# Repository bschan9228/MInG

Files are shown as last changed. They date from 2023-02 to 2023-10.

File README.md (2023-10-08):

# MInG
MInG is a hardware password manager. More information can be found below: 

https://bschan9228.github.io/MInG/

https://docs.google.com/document/d/1XQeUcRW4mPYvgZ0W_UPjm9wVBVjZgWeWX6C9jlaiZSg/edit



## Folder Structure
    .
    ├── Hardware                # Project hardware and PCB
    │   ├── Final               # Final PCB 
    │   └── Prototype           # Prototype PCB's
    └── Software
            ├── Experimental    # Experimental firmware for the device
            └── Final           # Final firmware for the device

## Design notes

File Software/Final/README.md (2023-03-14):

# Final Software
Finalized software for MInG. Built with ESP-IDF.

Default access point username: MInG 

Default access point password: mypassword 



## Features

### Password Management System
- Stores all credentials in flash memory
- Search bar to look up credentials
- Add new credentials through form
- Delete button to remove credentials
- 192.168.4.1/pm

<kbd></kbd>

### Config
- Change SSID's name and password
  - Stored in NVS
  - Please use reasonable SSID name/password, otherwise device may not work
- Send any HID text wirelessly
- 192.168.4.1

<kbd></kbd>

### Keyboard
- Type any character into target device. Worked on all tested USB-A and USB-C devices that supports keyboards
- Only characters and special characters have been implemented (no delete, tab, F-keys, etc.)
- Only typing on a physical keyboard has been implemented. Tapping on the virtual keyboard will not work. 
- 192.168.4.1/keyboard

<kbd></kbd>

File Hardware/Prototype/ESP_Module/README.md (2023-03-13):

# Module
Working ESP32-S3 Module USB-A device.



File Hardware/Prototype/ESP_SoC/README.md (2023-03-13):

# SoC
A working ESP32-S3 PCB with featuring USB-A and USB-C connectors.



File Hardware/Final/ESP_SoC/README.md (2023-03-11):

# Final PCB
Final PCB design for the ESP32 PCB. Currently Have not been produced. Includes reverse polarity protection.

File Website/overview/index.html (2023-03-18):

Home (https://bschan9228.github.io/MInG/index.html)

Projects ⟱

Projects overview (https://bschan9228.github.io/MInG/Website/overview/index.html) Projects Video (https://bschan9228.github.io/MInG/Website/Video/index.html) References (https://bschan9228.github.io/MInG/Website/References/index.html)

Technical Workshop ⟱

Embedding the Embedded (https://bschan9228.github.io/MInG/Website/workshop/index.html)

About us (https://bschan9228.github.io/MInG/Website/us/index.html)

## Presentation Slides

## Project Poster

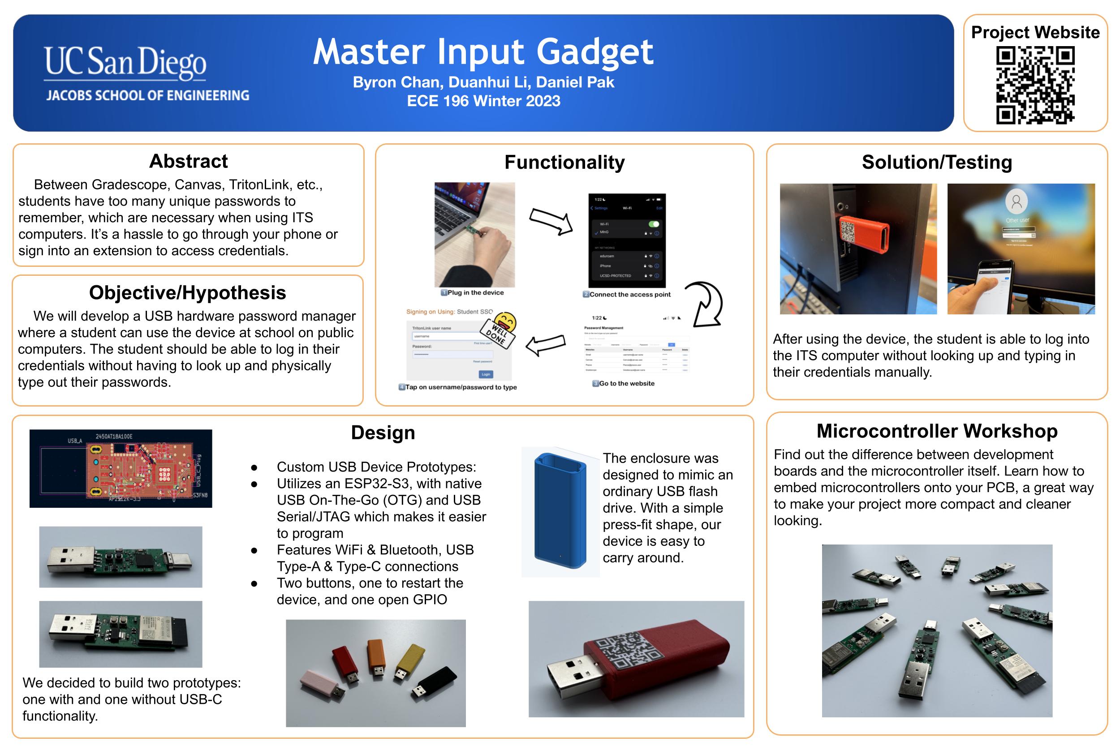
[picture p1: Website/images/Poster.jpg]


## Work flow

This is how our device works



## ESP32-S3 SoC PCB

For our project, we used the ESP32-S3 MCU, which supports USB OTG and is capable of 2.4 GHz Wi-Fi and Bluetooth Low Energy 5.0





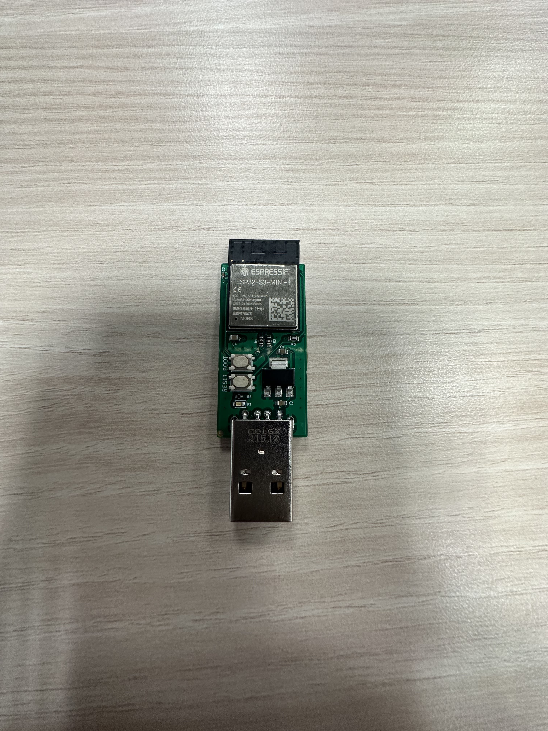
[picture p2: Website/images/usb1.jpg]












© UC San Diego: Jacobs School of Enginnering

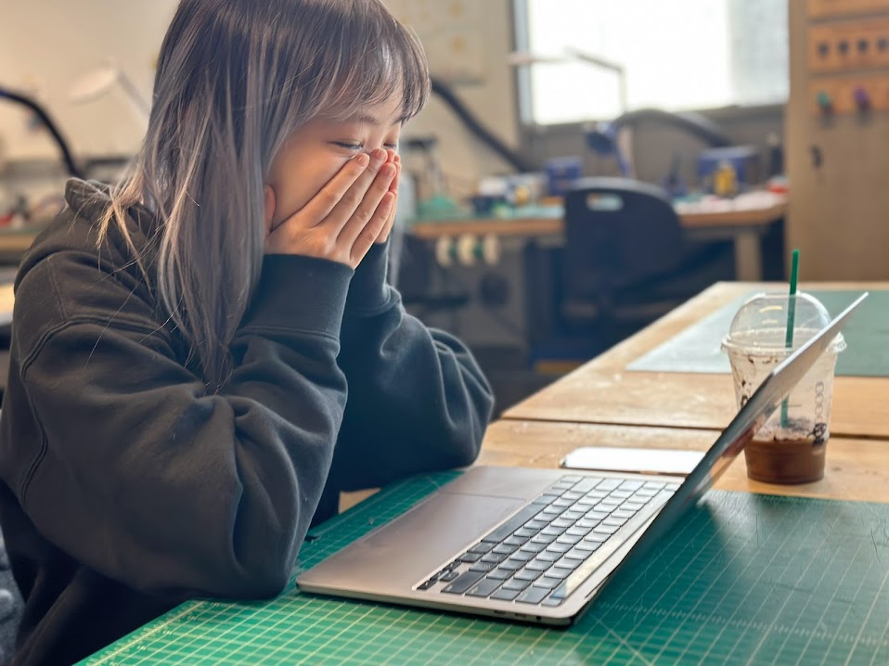
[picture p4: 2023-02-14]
Website/images/lori.png

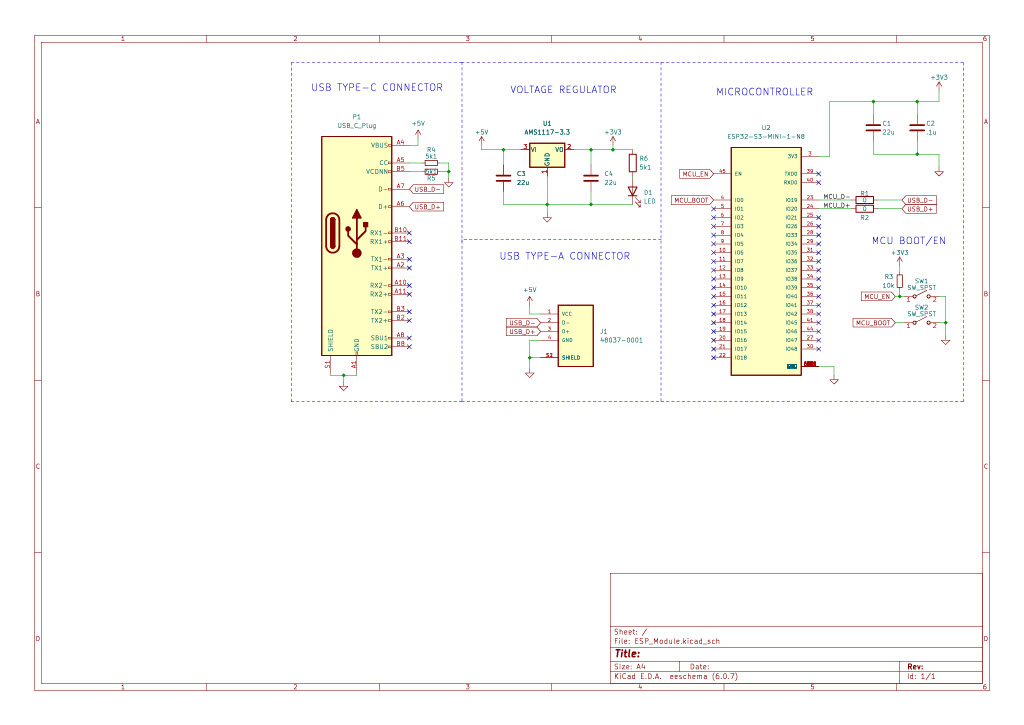
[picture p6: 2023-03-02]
Website/images/pcb1.jpg

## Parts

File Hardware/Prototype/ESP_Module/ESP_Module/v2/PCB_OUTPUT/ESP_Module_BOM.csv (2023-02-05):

Comment | Designator | Footprint | LCSC Part #
22u Unpolarized capacitor | C1,C3,C4 | C_0603_1608Metric | C59461
.1u Unpolarized capacitor | C2 | C_0402_1005Metric | C1525
LED Light emitting diode | D1 | LED_0603_1608Metric | C72043
48037-0001 | J1 | MOLEX_48037-0001 | C136455
USB_C_Plug USB Type-C Plug connector | P1 | USB_C_Plug_Molex_105444 | C319150
0 Resistor | R1,R2 | R_0603_1608Metric | C17168
10k Resistor, small symbol | R3 | R_0603_1608Metric | C25744
5k1 Resistor | R4,R5,R6 | R_0402_1005Metric | C25905
SW_SPST Single Pole Single Throw (SPST) switch | SW1,SW2 | SW_SPST_PTS810 | C92589
AMS1117-3.3 1A Low Dropout regulator, positive, 3.3V fixed output, SOT-223 | U1 | SOT-223-3_TabPin2 | C6186
ESP32-S3-MINI-1-N8 | U2 | XCVR_ESP32-S3-MINI-1-N8 | C2913206

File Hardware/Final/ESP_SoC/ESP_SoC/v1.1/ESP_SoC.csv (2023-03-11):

Comment | Designator | Footprint | LCSC Part # | Quantity
2450AT18A100E | AE1 | ANTC3216X140N | C89334 | 1 | =E2*F1
1u Unpolarized capacitor, small symbol | C1,C7,C11,C12,C13,C16 | C_0402_1005Metric | C52923 | 6 | =E3*F1
0.1u Unpolarized capacitor, small symbol | C2,C5,C6,C9,C10 | C_0402_1005Metric | C307331 | 5 | =E4*F1
3.3p Unpolarized capacitor, small symbol | C3,C4 | C_0402_1005Metric | C1565 | 2 | =E5*F1
10u Unpolarized capacitor, small symbol | C8 | C_0603_1608Metric | C19702 | 1 | =E6*F1
12p Unpolarized capacitor, small symbol | C14,C15 | C_0402_1005Metric | C1547 | 2 | =E7*F1
NSR0320 Schottky diode | D1,D2,D3 | D_SOD-323F | C48192 | 3 | =E8*F1
USB_A USB Type A connector | J1 | USB_A_CNCTech_1001-011-01101_Horizontal | C283548 | 1 | =E9*F1
Conn_01x01 Generic connector, single row, 01x01, script generated (kicad-library-utils/schlib/autogen/connector/) | J2,J3 | SolderWirePad_1x01_SMD_1x2mm |  | 2 | =E10*F1
2.2nH Inductor, small symbol | L1,L2 | L_0402_1005Metric | C91240 | 2 | =E11*F1
USB_C_Plug USB Type-C Plug connector | P1 | USB_C_Plug_Molex_105444 | C134082 | 1 | =E12*F1
0 Resistor, small symbol | R1,R3,R4 | R_0402_1005Metric | C17168 | 3 | =E13*F1
10k Resistor | R2 | R_0402_1005Metric | C25744 | 1 | =E14*F1
5k1 Resistor, small symbol | R5 | R_0402_1005Metric | C25905 | 1 | =E15*F1
DNP Resistor, small symbol | R6,R7 | R_0402_1005Metric |  | 2 | =E16*F1
RESET Single Pole Single Throw (SPST) switch | SW1 | SW_SPST_PTS810 | C221897 | 1 | =E17*F1
BOOT Single Pole Single Throw (SPST) switch | SW2 | SW_SPST_PTS810 | C221897 | 1 | =E18*F1
AP2112K-3.3 600mA low dropout linear regulator, with enable pin, 3.8V-6V input voltage range, 3.3V fixed positive output, SOT-23-5 | U1 | SOT-23-5 | C51118 | 1 | =E19*F1
ESP32-S3FN8 | U2 | QFN40P700X700X90-57N |  | 1 | =E20*F1
WS2812-2020 | U3 | LED_WS2812-2020 | C2976072 | 1 | =E21*F1
40MHz Four pin crystal, GND on pins 2 and 4 | Y1 | Crystal_SMD_2016-4Pin_2.0x1.6mm | C255898 | 1 | =E22*F1

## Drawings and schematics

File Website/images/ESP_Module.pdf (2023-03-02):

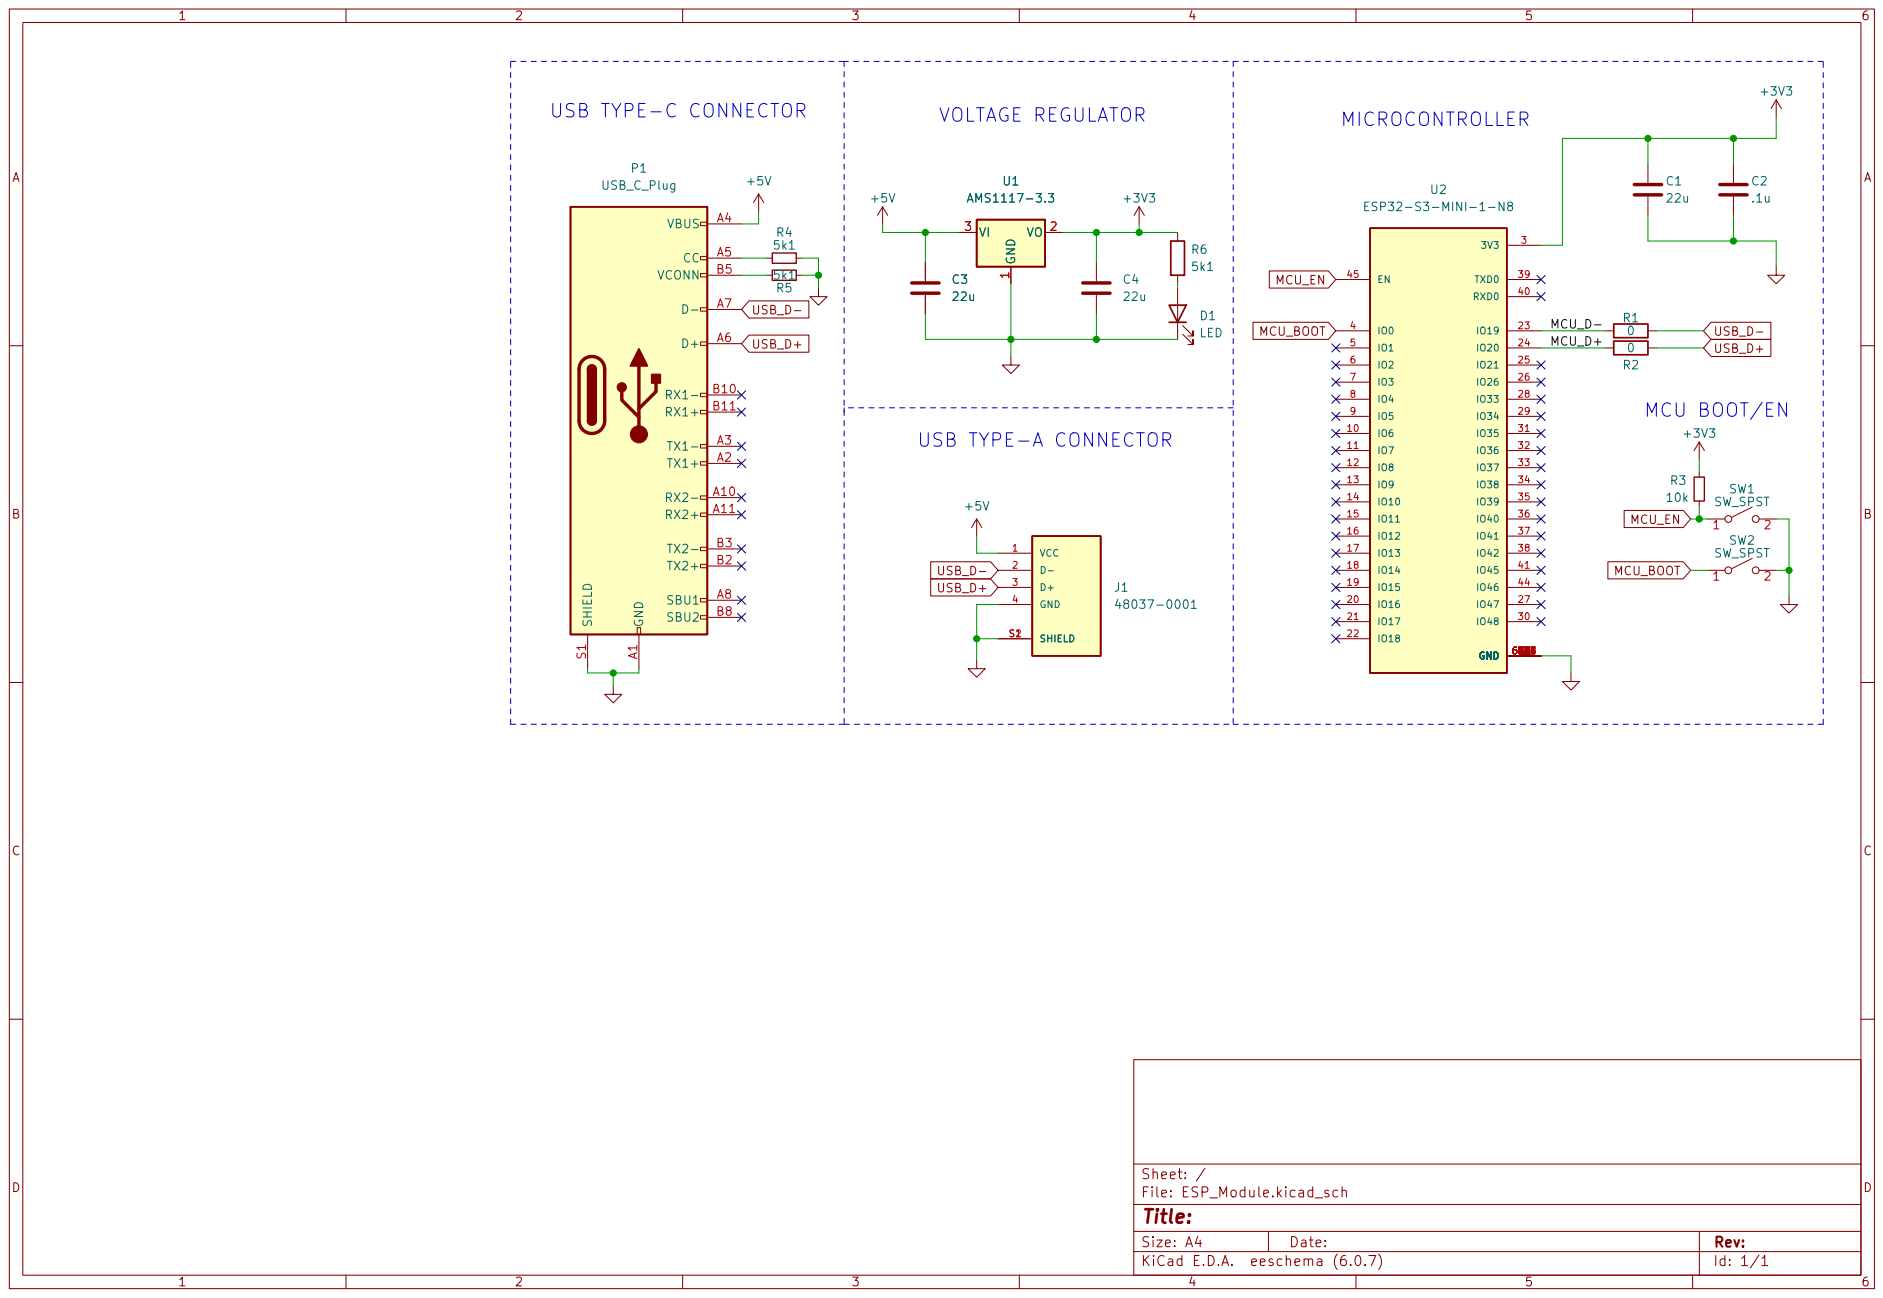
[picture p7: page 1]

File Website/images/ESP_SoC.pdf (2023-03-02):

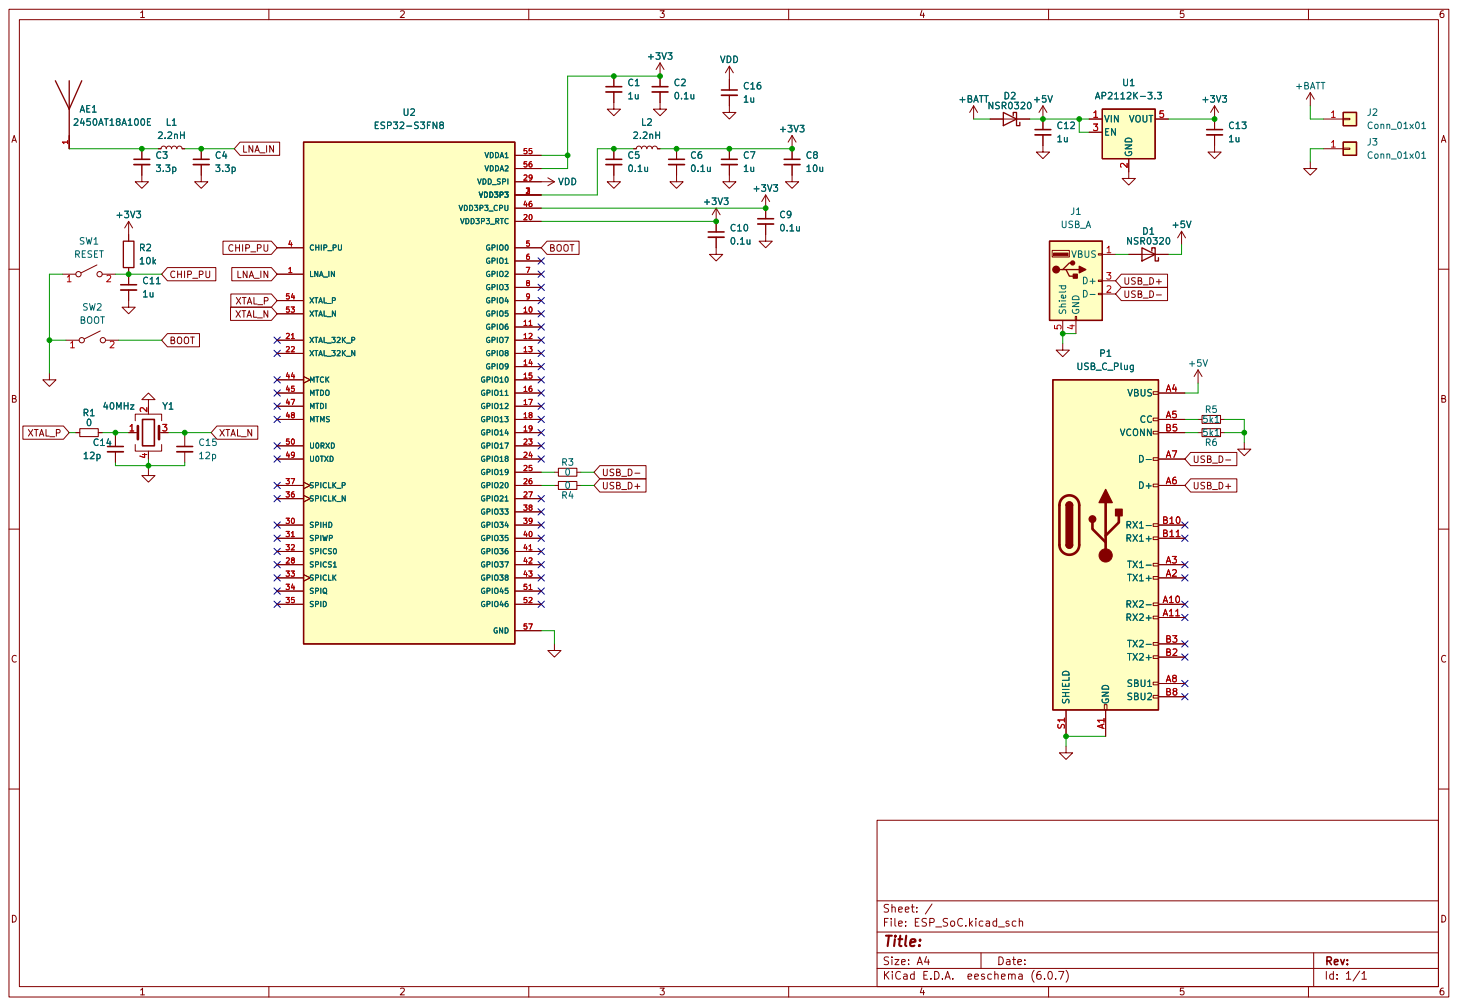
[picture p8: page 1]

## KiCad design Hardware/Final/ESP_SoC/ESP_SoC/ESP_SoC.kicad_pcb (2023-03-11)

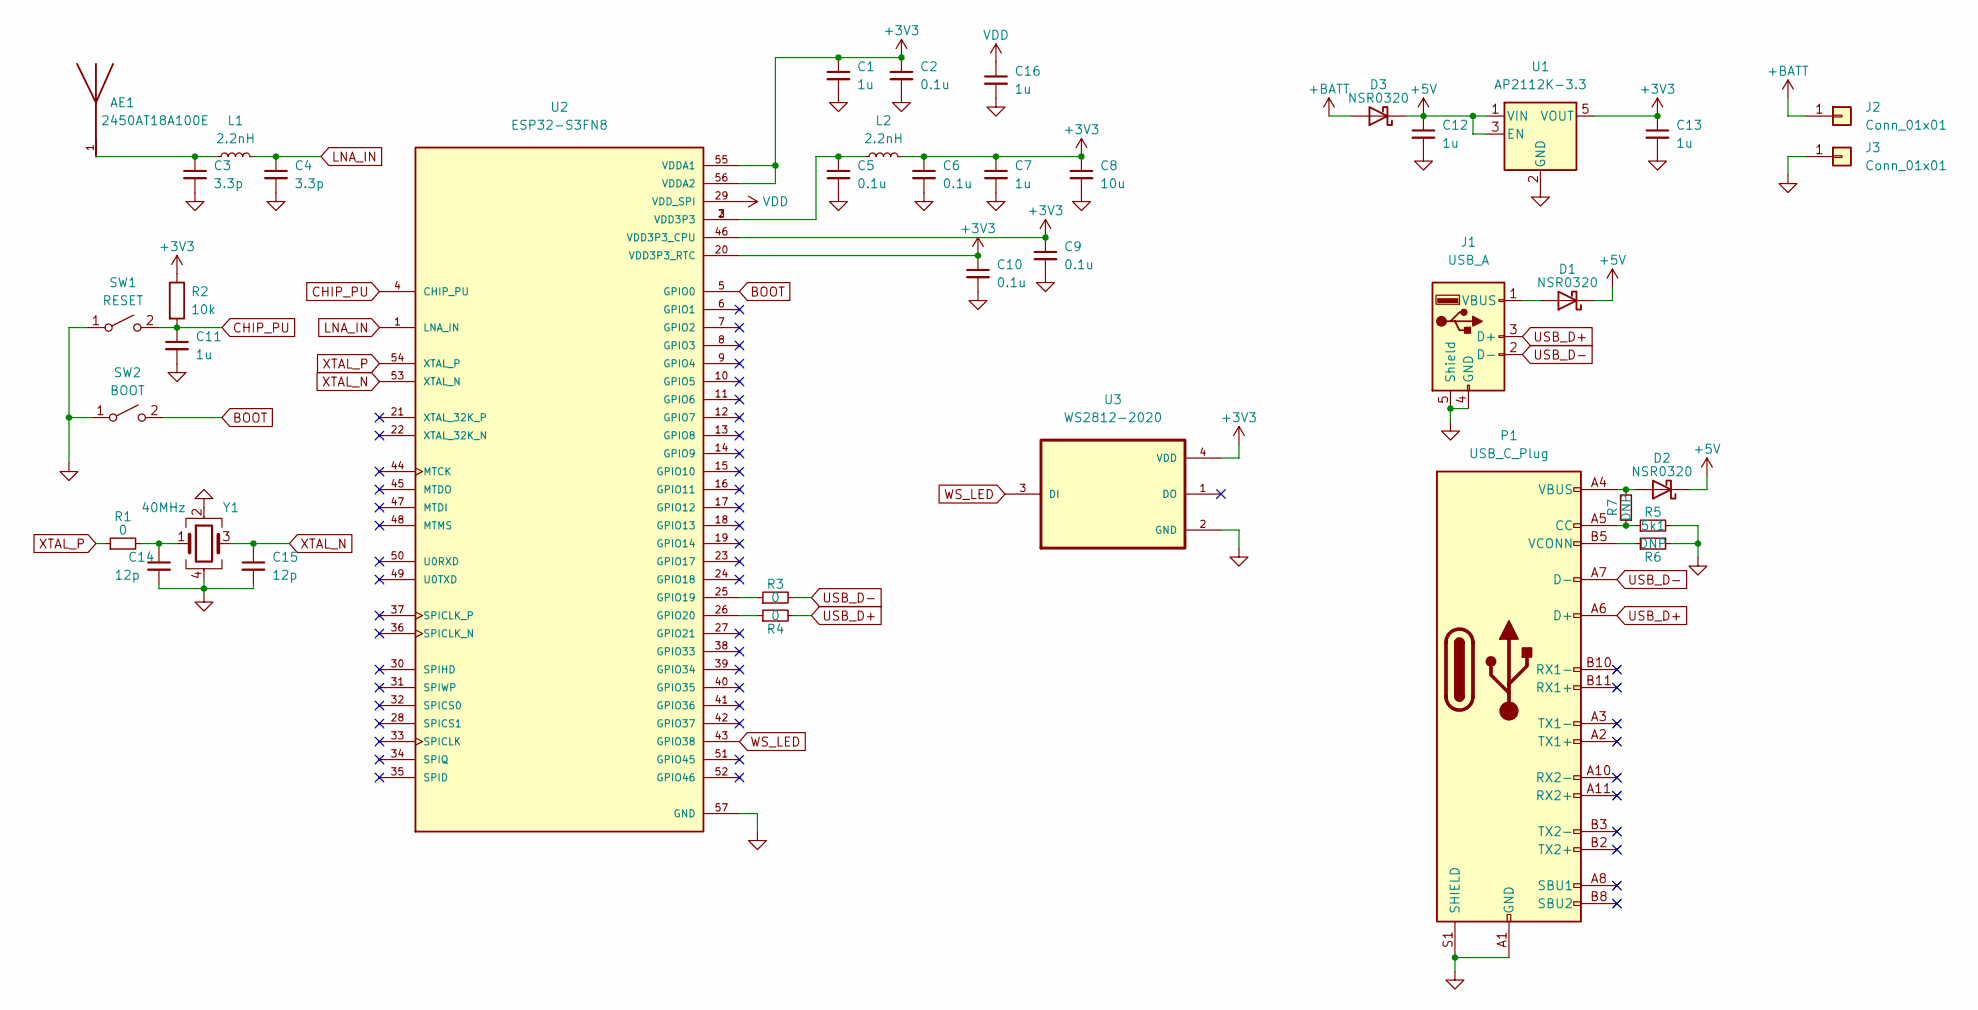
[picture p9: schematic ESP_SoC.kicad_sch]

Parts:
AE1: 2450AT18A100E; ANTC3216X140N; PARTREV 1.3; LCSC Part # C89334
C1, C7, C11, C12, C13, C16: 1u; C_0402_1005Metric; LCSC Part # C52923
C2, C5, C6, C9, C10: 0.1u; C_0402_1005Metric; LCSC Part # C307331
C3, C4: 3.3p; C_0402_1005Metric; LCSC Part # C1565
C8: 10u; C_0603_1608Metric; LCSC Part # C19702
C14, C15: 12p; C_0402_1005Metric; LCSC Part # C1547
D1, D2, D3: NSR0320; D_SOD-323F; LCSC Part # C48192
J1: USB_A; USB_A_CNCTech_1001-011-01101_Horizontal; LCSC Part # C283548
J2, J3: Conn_01x01; SolderWirePad_1x01_SMD_1x2mm
L1, L2: 2.2nH; L_0402_1005Metric; LCSC Part # C91240
P1: USB_C_Plug; USB_C_Plug_Molex_105444; LCSC Part # C134082
R1, R3, R4: 0; R_0402_1005Metric; LCSC Part # C17168
R2: 10k; R_0402_1005Metric; LCSC Part # C25744
R5: 5k1; R_0402_1005Metric; LCSC Part # C25905
R6, R7: DNP; R_0402_1005Metric
SW1: RESET; SW_SPST_PTS810; LCSC Part # C221897
SW2: BOOT; SW_SPST_PTS810; LCSC Part # C221897
U1: AP2112K-3.3; SOT-23-5; LCSC Part # C51118
U2: ESP32-S3FN8; QFN40P700X700X90-57N
U3: WS2812-2020; LED_WS2812-2020; PARTREV V1.3; LCSC Part # C2976072
Y1: 40MHz; Crystal_SMD_2016-4Pin_2.0x1.6mm; LCSC Part # C255898

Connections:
+3V3: C1.1, C2.1, C6.1, C7.1, C8.1, C9.1, C10.1, C13.1, L2.2, R2.1, U1.5 (VOUT), U2.20 (VDD3P3_RTC), U2.46 (VDD3P3_CPU), U2.55 (VDDA1), U2.56 (VDDA2), U3.4 (VDD)
+5V: C12.1, D1.1 (K), D2.1 (K), D3.1 (K), U1.1 (VIN), U1.3 (EN)
+BATT: D3.2 (A), J2.1
BOOT: SW2.2 (B), U2.5 (GPIO0)
CHIP_PU: C11.1, R2.2, SW1.2 (B), U2.4 (CHIP_PU)
GND: C1.2, C2.2, C3.2, C4.2, C5.2, C6.2, C7.2, C8.2, C9.2, C10.2, C11.2, C12.2, C13.2, C14.2, C15.2, C16.2, J1.4 (GND), J1.5 (Shield), J3.1, P1.A1 (GND), P1.A12 (GND), P1.B1 (GND), P1.B12 (GND), P1.S1 (SHIELD), R5.2, R6.2, SW1.1 (A), SW2.1 (A), U1.2 (GND), U2.57 (GND), U3.2 (GND), Y1.2, Y1.4
LNA_IN: C4.1, L1.2, U2.1 (LNA_IN)
unnamed: AE1.1, C3.1, L1.1
unnamed: C5.1, L2.1, U2.2 (VDD3P3), U2.3 (VDD3P3)
unnamed: C14.1, R1.2, Y1.1
unnamed: D1.2 (A), J1.1 (VBUS)
unnamed: D2.2 (A), P1.A4 (VBUS), P1.A9 (VBUS), P1.B4 (VBUS), P1.B9 (VBUS), R7.2
unnamed: P1.A5 (CC), R5.1, R7.1
unnamed: P1.B5 (VCONN), R6.1
unnamed: R3.1, U2.25 (GPIO19)
unnamed: R4.1, U2.26 (GPIO20)
USB_D+: J1.3 (D+), P1.A6 (D+), R4.2
USB_D-: J1.2 (D-), P1.A7 (D-), R3.2
VDD: C16.1, U2.29 (VDD_SPI)
WS_LED: U2.43 (GPIO38), U3.3 (DI)
XTAL_N: C15.1, U2.53 (XTAL_N), Y1.3
XTAL_P: R1.1, U2.54 (XTAL_P)

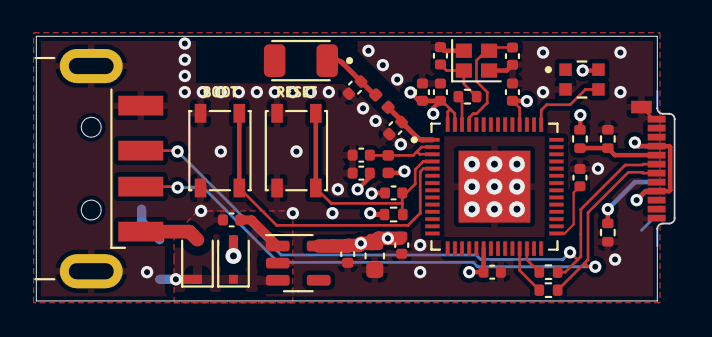
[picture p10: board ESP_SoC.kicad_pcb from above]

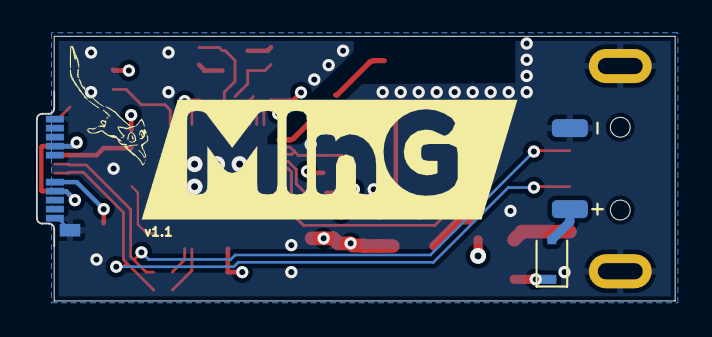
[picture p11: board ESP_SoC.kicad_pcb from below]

Board: 4 copper layers, 35.5 x 14.7 mm, 40 parts (4 on the bottom side), 22 nets.

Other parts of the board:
kibuzzard-64092D35: G***; kibuzzard-64092D35

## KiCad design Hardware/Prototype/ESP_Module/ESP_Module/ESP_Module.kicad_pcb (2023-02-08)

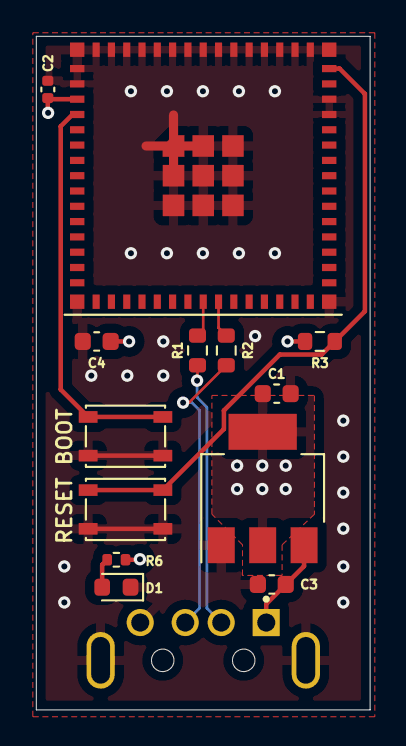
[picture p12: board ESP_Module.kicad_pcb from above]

Board: 4 copper layers, 18.5 x 37.4 mm, 14 parts (0 on the bottom side), 10 nets.

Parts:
C1, C3, C4: 22u; C_0603_1608Metric
C2: .1u; C_0402_1005Metric
D1: LED; LED_0603_1608Metric
J1: 48037-0001; MOLEX_48037-0001
R1, R2: 0; R_0603_1608Metric
R3: 10k; R_0603_1608Metric
R6: 5k1; R_0402_1005Metric
SW1, SW2: SW_SPST; SW_SPST_PTS810
U1: AMS1117-3.3; SOT-223-3_TabPin2
U2: ESP32-S3-MINI-1-N8; XCVR_ESP32-S3-MINI-1-N8

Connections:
+3V3: C1.1, C2.1, C4.1, R3.1, R6.1, U1.2 (VO), U2.3 (3V3)
+5V: C3.1, J1.1 (VCC), U1.3 (VI)
/MCU_D+: R2.1, U2.24 (IO20)
/MCU_D-: R1.1, U2.23 (IO19)
GND: C1.2, C2.2, C3.2, C4.2, D1.1 (K), J1.4 (GND), J1.S1 (SHIELD), J1.S2 (SHIELD), SW1.2 (B), SW2.2 (B), U1.1 (GND), U2.1 (GND), U2.2 (GND), U2.42 (GND), U2.43 (GND), U2.46 (GND), U2.47 (GND), U2.48 (GND), U2.49 (GND), U2.50 (GND), U2.51 (GND), U2.52 (GND), U2.53 (GND), U2.54 (GND), U2.55 (GND), U2.56 (GND), U2.57 (GND), U2.58 (GND), U2.59 (GND), U2.60 (GND), U2.61 (GND), U2.61_1 (GND), U2.61_2 (GND), U2.61_3 (GND), U2.61_4 (GND), U2.61_5 (GND), U2.61_6 (GND), U2.61_7 (GND), U2.61_8 (GND), U2.62 (GND), U2.63 (GND), U2.64 (GND), U2.65 (GND)
MCU_BOOT: SW2.1 (A), U2.4 (IO0)
MCU_EN: R3.2, SW1.1 (A), U2.45 (EN)
unnamed: D1.2 (A), R6.2
USB_D+: J1.3 (D+), R2.2
USB_D-: J1.2 (D-), R1.2

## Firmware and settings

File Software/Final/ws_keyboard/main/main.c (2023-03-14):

#include <esp_wifi.h>
#include <esp_event.h>
#include <esp_log.h>
#include <esp_system.h>
#include <nvs_flash.h>
#include <sys/param.h>
#include "esp_netif.h"
#include "esp_eth.h"

#include <esp_http_server.h>

#include <string.h>
#include "freertos/FreeRTOS.h"
#include "freertos/task.h"
#include "esp_mac.h"

#include "lwip/err.h"
#include "lwip/sys.h"

#include <stdlib.h>
#include "tinyusb.h"
#include "class/hid/hid_device.h"
#include "driver/gpio.h"

#include <cJSON.h>

#include <stdio.h>
#include "esp_vfs.h"
#include "esp_vfs_fat.h"

#include <inttypes.h>
#include "esp_system.h"
#include "nvs_flash.h"
#include "nvs.h"

extern const char root_start[] asm("_binary_root_html_start");
extern const char root_end[] asm("_binary_root_html_end");
extern const char root_js_start[] asm("_binary_root_js_start");
extern const char root_js_end[] asm("_binary_root_js_end");

extern const char keyboard_start[] asm("_binary_keyboard_html_start");
extern const char keyboard_end[] asm("_binary_keyboard_html_end");
extern const char keyboard_js_start[] asm("_binary_keyboard_js_start");
extern const char keyboard_js_end[] asm("_binary_keyboard_js_end");

extern const char pm_start[] asm("_binary_pm_html_start");
extern const char pm_end[] asm("_binary_pm_html_end");
extern const char pm_js_start[] asm("_binary_pm_js_start");
extern const char pm_js_end[] asm("_binary_pm_js_end");

#define EXAMPLE_ESP_WIFI_SSID CONFIG_ESP_WIFI_SSID
#define EXAMPLE_ESP_WIFI_PASS CONFIG_ESP_WIFI_PASSWORD
#define EXAMPLE_ESP_WIFI_CHANNEL CONFIG_ESP_WIFI_CHANNEL
#define EXAMPLE_MAX_STA_CONN CONFIG_ESP_MAX_STA_CONN

// WL + FATFS
static wl_handle_t s_wl_handle = WL_INVALID_HANDLE;
const char *base_path = "/spiflash";

static const char *TAG = "console";

//------------------------- JSON -------------------------//
char *create_user(char *application, char *username)
{
    char *string = NULL;
    cJSON *app = NULL;
    cJSON *type = NULL;
    cJSON *website = NULL;
    cJSON *data = NULL;

    cJSON *user = cJSON_CreateObject();

    app = cJSON_CreateString("pm");
    cJSON_AddItemToObject(user, "app", app);

    type = cJSON_CreateString("insertUser");
    cJSON_AddItemToObject(user, "type", type);

    website = cJSON_CreateString(application);
    cJSON_AddItemToObject(user, "website", website);

    data = cJSON_CreateString(username);
    cJSON_AddItemToObject(user, "data", data);

    string = cJSON_Print(user);

    return string;
}

//------------------------- USB HID -------------------------//

#define TUSB_DESC_TOTAL_LEN (TUD_CONFIG_DESC_LEN + CFG_TUD_HID * TUD_HID_DESC_LEN)

/**
 * @brief HID report descriptor
 *
 * In this example we implement Keyboard + Mouse HID device,
 * so we must define both report descriptors
 */
const uint8_t hid_report_descriptor[] = {
    TUD_HID_REPORT_DESC_KEYBOARD(HID_REPORT_ID(HID_ITF_PROTOCOL_KEYBOARD)),
    TUD_HID_REPORT_DESC_MOUSE(HID_REPORT_ID(HID_ITF_PROTOCOL_MOUSE))};

/**
 * @brief Configuration descriptor
 *
 * This is a simple configuration descriptor that defines 1 configuration and 1 HID interface
 */
static const uint8_t hid_configuration_descriptor[] = {
    // Configuration number, interface count, string index, total length, attribute, power in mA
    TUD_CONFIG_DESCRIPTOR(1, 1, 0, TUSB_DESC_TOTAL_LEN, TUSB_DESC_CONFIG_ATT_REMOTE_WAKEUP, 100),

    // Interface number, string index, boot protocol, report descriptor len, EP In address, size & polling interval
    TUD_HID_DESCRIPTOR(0, 0, false, sizeof(hid_report_descriptor), 0x81, 16, 10),
};

/********* TinyUSB HID callbacks ***************/

// Invoked when received GET HID REPORT DESCRIPTOR request
// Application return pointer to descriptor, whose contents must exist long enough for transfer to complete
uint8_t const *tud_hid_descriptor_report_cb(uint8_t instance)
{
    // We use only one interface and one HID report descriptor, so we can ignore parameter 'instance'
    return hid_report_descriptor;
}

// Invoked when received GET_REPORT control request
// Application must fill buffer report's content and return its length.
// Return zero will cause the stack to STALL request
uint16_t tud_hid_get_report_cb(uint8_t instance, uint8_t report_id, hid_report_type_t report_type, uint8_t *buffer, uint16_t reqlen)
{
    (void)instance;
    (void)report_id;
    (void)report_type;
    (void)buffer;
    (void)reqlen;

    return 0;
}

// Invoked when received SET_REPORT control request or
// received data on OUT endpoint ( Report ID = 0, Type = 0 )
void tud_hid_set_report_cb(uint8_t instance, uint8_t report_id, hid_report_type_t report_type, uint8_t const *buffer, uint16_t bufsize)
{
}

/********* Application ***************/

typedef enum
{
    MOUSE_DIR_RIGHT,
    MOUSE_DIR_DOWN,
    MOUSE_DIR_LEFT,
    MOUSE_DIR_UP,
    MOUSE_DIR_MAX,
} mouse_dir_t;

#define DISTANCE_MAX 125
#define DELTA_SCALAR 5

static void mouse_draw_square_next_delta(int8_t *delta_x_ret, int8_t *delta_y_ret)
{
    static mouse_dir_t cur_dir = MOUSE_DIR_RIGHT;
    static uint32_t distance = 0;

    // Calculate next delta
    if (cur_dir == MOUSE_DIR_RIGHT)
    {
        *delta_x_ret = DELTA_SCALAR;
        *delta_y_ret = 0;
    }
    else if (cur_dir == MOUSE_DIR_DOWN)
    {
        *delta_x_ret = 0;
        *delta_y_ret = DELTA_SCALAR;
    }
    else if (cur_dir == MOUSE_DIR_LEFT)
    {
        *delta_x_ret = -DELTA_SCALAR;
        *delta_y_ret = 0;
    }
    else if (cur_dir == MOUSE_DIR_UP)
    {
        *delta_x_ret = 0;
        *delta_y_ret = -DELTA_SCALAR;
    }

    // Update cumulative distance for current direction
    distance += DELTA_SCALAR;
    // Check if we need to change direction
    if (distance >= DISTANCE_MAX)
    {
        distance = 0;
        cur_dir++;
        if (cur_dir == MOUSE_DIR_MAX)
        {
            cur_dir = 0;
        }
    }
}

static void app_send_hid_demo(void)
{
    // Keyboard output: Send key 'a/A' pressed and released
    ESP_LOGI(TAG, "Sending Keyboard report");
    uint8_t keycode[6] = {HID_KEY_A};
    tud_hid_keyboard_report(HID_ITF_PROTOCOL_KEYBOARD, 0, keycode);
    vTaskDelay(pdMS_TO_TICKS(50));
    tud_hid_keyboard_report(HID_ITF_PROTOCOL_KEYBOARD, 0, NULL);

    // Mouse output: Move mouse cursor in square trajectory
    ESP_LOGI(TAG, "Sending Mouse report");
    int8_t delta_x;
    int8_t delta_y;
    for (int i = 0; i < (DISTANCE_MAX / DELTA_SCALAR) * 4; i++)
    {
        // Get the next x and y delta in the draw square pattern
        mouse_draw_square_next_delta(&delta_x, &delta_y);
        tud_hid_mouse_report(HID_ITF_PROTOCOL_MOUSE, 0x00, delta_x, delta_y, 0, 0);
        vTaskDelay(pdMS_TO_TICKS(20));
    }
}

uint8_t const conv_table[128][2] = {HID_ASCII_TO_KEYCODE};

static void send_character(char c)
{
    uint8_t keycode[6] = {0};
    uint8_t modifier = 0;
    if (conv_table[c + 0][0])
        modifier = KEYBOARD_MODIFIER_LEFTSHIFT;
    keycode[0] = conv_table[c + 0][1];

    tud_hid_keyboard_report(HID_ITF_PROTOCOL_KEYBOARD, modifier, keycode);
    // Can speed up by removing null report and adding more keycodes
    // tud_hid_keyboard_report(HID_ITF_PROTOCOL_KEYBOARD, 0, NULL);
    // vTaskDelay(pdMS_TO_TICKS(10));
}

static void app_send_string(uint8_t *data, int start, size_t len)
{
    // Keyboard sends inputted string
    ESP_LOGI(TAG, "Sending Keyboard report");
    for (int i = start; i < len; i++)
    {
        if (data[i] == data[i - 1])
        {
            tud_hid_keyboard_report(HID_ITF_PROTOCOL_KEYBOARD, 0, NULL);
            vTaskDelay(pdMS_TO_TICKS(15));
        }

        send_character(data[i]);
        vTaskDelay(pdMS_TO_TICKS(20));
    }
    tud_hid_keyboard_report(HID_ITF_PROTOCOL_KEYBOARD, 0, NULL);
    vTaskDelay(pdMS_TO_TICKS(20));
}

void send_pass_hid(char *website, char *data)
{
    char line[128];
    FILE *f = fopen("/spiflash/cred.txt", "rb");
    website++; // used to get past quotes
    data++;    // ^
    website[strlen(website) - 1] = 0;
    data[strlen(data) - 1] = 0;

    // app_send_string((uint8_t *)website, 0, strlen(website));

    // app_send_string((uint8_t *)data, 0, strlen(data));

    while (fgets(line, sizeof(line), f) != NULL)
    {
        char *pos = strchr(line, ':');

        if (pos)
        {
            *pos = '\0';
        }
        pos++;
        pos[strlen(pos) - 1] = 0;

        char *pos2 = strchr(pos, ':');
        if (pos2)
        {
            *pos2 = '\0';
        }
        pos2++;

        ESP_LOGI(TAG, "User: '%s'", line);
        ESP_LOGI(TAG, "Pass: '%s'", pos);
        // send
        if (strcmp(line, website) == 0 && strcmp(pos, data) == 0)
        {
            fclose(f);
            app_send_string((uint8_t *)pos2, 0, strlen(pos2));
            return;
        }
    }

    fclose(f);
    return;
}

// ----------- FLASH ----------- //
void add_user_flash(char *website, char *username, char *password)
{
    website++;
    username++;
    password++;
    website[strlen(website) - 1] = 0;
    username[strlen(username) - 1] = 0;
    password[strlen(password) - 1] = 0;

    // app_send_string((uint8_t *)website, 0, strlen(website));
    // app_send_string((uint8_t *)username, 0, strlen(username));
    // app_send_string((uint8_t *)password, 0, strlen(password));

    FILE *f = fopen("/spiflash/cred.txt", "a");
    fprintf(f, "%s:%s:%s\n", website, username, password);
    fclose(f);
    return;
}

void delete_user_flash(char *website, char *data, char *password)
{
    char line[128];
    website++; // used to get past quotes
    data++;    // ^
    website[strlen(website) - 1] = 0;
    data[strlen(data) - 1] = 0;

    FILE *f = fopen("/spiflash/cred.txt", "rb");
    FILE *temp = fopen("/spiflash/temp.txt", "wb");

    while (fgets(line, sizeof(line), f) != NULL)
    {
        char *pos = strchr(line, ':');

        if (pos)
        {
            *pos = '\0';
        }
        pos++;
        pos[strlen(pos) - 1] = 0;

        char *pos2 = strchr(pos, ':');
        if (pos2)
        {
            *pos2 = '\0';
        }
        pos2++;

        if (strcmp(line, website) == 0 && strcmp(pos, data) == 0)
        {
            continue;
        }
        // fputs(line, temp);
        fprintf(temp, "%s:%s:%s\n", line, pos, pos2);
    }

    fclose(f);
    fclose(temp);

    // rewrite to cred.txt
    FILE *f2 = fopen("/spiflash/cred.txt", "w");
    FILE *temp2 = fopen("/spiflash/temp.txt", "r");

    while ((fgets(line, sizeof(line), temp2)) != NULL)
    {
        fputs(line, f2);
    }
    fclose(f2);
    fclose(temp2);

    return;
}

// Configure SSID
void config_SSID(char *data)
{
    data++;
    data[strlen(data) - 1] = 0;

    if (strlen(data) > 0 && strlen(data) < 32)
    {
        nvs_handle_t my_handle;
        esp_err_t err = nvs_open("storage", NVS_READWRITE, &my_handle);
        nvs_set_str(my_handle, "ssid", data);
        nvs_commit(my_handle);
        nvs_close(my_handle);
    }

    return;
}

void config_password(char *data)
{
    data++;
    data[strlen(data) - 1] = 0;

    if (strlen(data) >= 8 && strlen(data) < 64)
    {
        nvs_handle_t my_handle;
        esp_err_t err = nvs_open("storage", NVS_READWRITE, &my_handle);
        nvs_set_str(my_handle, "password", data);
        nvs_commit(my_handle);
        nvs_close(my_handle);
    }

    return;
}

// --------------------------- Websockets --------------------------- //
/* A simple example that demonstrates using websocket echo server
 */

struct async_resp_arg
{
    httpd_handle_t hd;
    int fd;
};

static void send_users(void *arg)
{

    struct async_resp_arg *resp_arg = arg;
    httpd_handle_t hd = resp_arg->hd;
    int fd = resp_arg->fd;
    char line[128];

    FILE *f = fopen("/spiflash/cred.txt", "rb");

    while (fgets(line, sizeof(line), f) != NULL)
    {
        // fgets(line, sizeof(line), f);
        // strip stuff
        char *pos = strchr(line, ':');

        if (pos)
        {
            *pos = '\0';
        }
        pos++;
        pos[strlen(pos) - 1] = 0;

        char *pos2 = strchr(pos, ':');
        if (pos2)
        {
            *pos2 = '\0';
        }
        // pos2++;

        ESP_LOGI(TAG, "User: '%s'", line);
        ESP_LOGI(TAG, "Pass: '%s'", pos);
        // send

        char *data = create_user(line, pos);
        httpd_ws_frame_t ws_pkt;
        memset(&ws_pkt, 0, sizeof(httpd_ws_frame_t));
        ws_pkt.payload = (uint8_t *)data;
        ws_pkt.len = strlen(data);
        ws_pkt.type = HTTPD_WS_TYPE_TEXT;

        httpd_ws_send_frame_async(hd, fd, &ws_pkt);
    }

    fclose(f);
    free(resp_arg);
}

static esp_err_t trigger_async_send(httpd_handle_t handle, httpd_req_t *req)
{
    struct async_resp_arg *resp_arg = malloc(sizeof(struct async_resp_arg));
    resp_arg->hd = req->handle;
    resp_arg->fd = httpd_req_to_sockfd(req);
    return httpd_queue_work(handle, send_users, resp_arg);
}
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
void app_main(void)
{
    static httpd_handle_t server = NULL;

    ESP_ERROR_CHECK(nvs_flash_init());
    ESP_ERROR_CHECK(esp_netif_init());
    ESP_ERROR_CHECK(esp_event_loop_create_default());

    /* This helper function configures Wi-Fi or Ethernet, as selected in menuconfig.
     * Read "Establishing Wi-Fi or Ethernet Connection" section in
     * examples/protocols/README.md for more information about this function.
     */
    // ESP_ERROR_CHECK(example_connect());
    ESP_LOGI(TAG, "ESP_WIFI_MODE_AP");
    ESP_ERROR_CHECK(wifi_init_softap());

    /* Register event handlers to stop the server when Wi-Fi or Ethernet is disconnected,
     * and re-start it upon connection.
     */
#ifdef CONFIG_EXAMPLE_CONNECT_WIFI
    ESP_ERROR_CHECK(esp_event_handler_register(IP_EVENT, IP_EVENT_STA_GOT_IP, &connect_handler, &server));
    ESP_ERROR_CHECK(esp_event_handler_register(WIFI_EVENT, WIFI_EVENT_STA_DISCONNECTED, &disconnect_handler, &server));
#endif // CONFIG_EXAMPLE_CONNECT_WIFI
#ifdef CONFIG_EXAMPLE_CONNECT_ETHERNET
    ESP_ERROR_CHECK(esp_event_handler_register(IP_EVENT, IP_EVENT_ETH_GOT_IP, &connect_handler, &server));
    ESP_ERROR_CHECK(esp_event_handler_register(ETH_EVENT, ETHERNET_EVENT_DISCONNECTED, &disconnect_handler, &server));
#endif // CONFIG_EXAMPLE_CONNECT_ETHERNET

    /* Start the server for the first time */
    server = start_webserver();

    // Tiny USB
    ESP_LOGI(TAG, "USB initialization");
    const tinyusb_config_t tusb_cfg = {
        .device_descriptor = NULL,
        .string_descriptor = NULL,
        .external_phy = false,
        .configuration_descriptor = hid_configuration_descriptor,
    };

    ESP_ERROR_CHECK(tinyusb_driver_install(&tusb_cfg));
    ESP_LOGI(TAG, "USB initialization DONE");

    // FATFS
    const esp_vfs_fat_mount_config_t mount_config = {
        .max_files = 4,
        .format_if_mount_failed = true,
        .allocation_unit_size = CONFIG_WL_SECTOR_SIZE};
    esp_err_t err = esp_vfs_fat_spiflash_mount_rw_wl(base_path, "storage", &mount_config, &s_wl_handle);
    // err = esp_vfs_fat_spiflash_mount_rw_wl(base_path, "storage", &mount_config, &s_wl_handle);

    // Write to file
    // FILE *f = fopen("/spiflash/cred.txt", "wb");
    // fputs("Gmail:username@user.name:gmail's password\nCanvas:Canvas@canvas.user:canvas pass\nPiazza:Piazza@piazza.user:huge piazza w\nGradescope:Gradescope@user.name:big L\n", f);
    // fclose(f);
    ESP_LOGI(TAG, "Check if file exists");
    FILE *f = fopen("/spiflash/cred.txt", "r");
    if (f == NULL)
    {
        ESP_LOGE(TAG, "File does not exist. Initializing.");
        FILE *f2 = fopen("/spiflash/cred.txt", "w");
        fputs("Gmail:username@user.name:gmail's password\nCanvas:Canvas@canvas.user:canvas pass\nPiazza:Piazza@piazza.user:huge piazza w\nGradescope:Gradescope@user.name:big L\n", f2);
        fclose(f2);
    }
    else
    {
        ESP_LOGE(TAG, "File exists");
    }
    fclose(f);
}

/*
Testing:
ip = "192.168.4.1" //?
ws = new WebSocket('ws://' + ip + '/ws');
ws.send("abc");
*/

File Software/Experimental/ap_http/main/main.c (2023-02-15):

/* Simple HTTP Server Example

   This example code is in the Public Domain (or CC0 licensed, at your option.)

   Unless required by applicable law or agreed to in writing, this
   software is distributed on an "AS IS" BASIS, WITHOUT WARRANTIES OR
   CONDITIONS OF ANY KIND, either express or implied.
*/

#include <esp_wifi.h>
#include <esp_event.h>
#include <esp_log.h>
#include <esp_system.h>
#include <nvs_flash.h>
#include <sys/param.h>
#include "nvs_flash.h"
#include "esp_netif.h"
#include "esp_eth.h"
#include "protocol_examples_common.h"
#include "esp_tls_crypto.h"
#include <esp_http_server.h>

#include <string.h>
#include "freertos/FreeRTOS.h"
#include "freertos/task.h"
#include "esp_mac.h"

#include "lwip/err.h"
#include "lwip/sys.h"

#define EXAMPLE_ESP_WIFI_SSID CONFIG_ESP_WIFI_SSID
#define EXAMPLE_ESP_WIFI_PASS CONFIG_ESP_WIFI_PASSWORD
#define EXAMPLE_ESP_WIFI_CHANNEL CONFIG_ESP_WIFI_CHANNEL
#define EXAMPLE_MAX_STA_CONN CONFIG_ESP_MAX_STA_CONN
/* A simple example that demonstrates how to create GET and POST
 * handlers for the web server.
 */

static const char *TAG = "example";

#if CONFIG_EXAMPLE_BASIC_AUTH

typedef struct
{
    char *username;
    char *password;
} basic_auth_info_t;

#define HTTPD_401 "401 UNAUTHORIZED" /*!< HTTP Response 401 */

static char *http_auth_basic(const char *username, const char *password)
{
    int out;
    char *user_info = NULL;
    char *digest = NULL;
    size_t n = 0;
    asprintf(&user_info, "%s:%s", username, password);
    if (!user_info)
    {
        ESP_LOGE(TAG, "No enough memory for user information");
        return NULL;
    }
    esp_crypto_base64_encode(NULL, 0, &n, (const unsigned char *)user_info, strlen(user_info));

    /* 6: The length of the "Basic " string
     * n: Number of bytes for a base64 encode format
     * 1: Number of bytes for a reserved which be used to fill zero
     */
    digest = calloc(1, 6 + n + 1);
    if (digest)
    {
        strcpy(digest, "Basic ");
        esp_crypto_base64_encode((unsigned char *)digest + 6, n, (size_t *)&out, (const unsigned char *)user_info, strlen(user_info));
    }
    free(user_info);
    return digest;
}

/* An HTTP GET handler */
static esp_err_t basic_auth_get_handler(httpd_req_t *req)
{
    char *buf = NULL;
    size_t buf_len = 0;
    basic_auth_info_t *basic_auth_info = req->user_ctx;

    buf_len = httpd_req_get_hdr_value_len(req, "Authorization") + 1;
    if (buf_len > 1)
    {
        buf = calloc(1, buf_len);
        if (!buf)
        {
            ESP_LOGE(TAG, "No enough memory for basic authorization");
            return ESP_ERR_NO_MEM;
        }

        if (httpd_req_get_hdr_value_str(req, "Authorization", buf, buf_len) == ESP_OK)
        {
            ESP_LOGI(TAG, "Found header => Authorization: %s", buf);
        }
        else
        {
            ESP_LOGE(TAG, "No auth value received");
        }

        char *auth_credentials = http_auth_basic(basic_auth_info->username, basic_auth_info->password);
        if (!auth_credentials)
        {
            ESP_LOGE(TAG, "No enough memory for basic authorization credentials");
            free(buf);
            return ESP_ERR_NO_MEM;
        }

        if (strncmp(auth_credentials, buf, buf_len))
        {
            ESP_LOGE(TAG, "Not authenticated");
            httpd_resp_set_status(req, HTTPD_401);
            httpd_resp_set_type(req, "application/json");
            httpd_resp_set_hdr(req, "Connection", "keep-alive");
            httpd_resp_set_hdr(req, "WWW-Authenticate", "Basic realm=\"Hello\"");
            httpd_resp_send(req, NULL, 0);
        }
        else
        {
            ESP_LOGI(TAG, "Authenticated!");
            char *basic_auth_resp = NULL;
            httpd_resp_set_status(req, HTTPD_200);
            httpd_resp_set_type(req, "application/json");
            httpd_resp_set_hdr(req, "Connection", "keep-alive");
            asprintf(&basic_auth_resp, "{\"authenticated\": true,\"user\": \"%s\"}", basic_auth_info->username);
            if (!basic_auth_resp)
            {
                ESP_LOGE(TAG, "No enough memory for basic authorization response");
                free(auth_credentials);
                free(buf);
                return ESP_ERR_NO_MEM;
            }
            httpd_resp_send(req, basic_auth_resp, strlen(basic_auth_resp));
            free(basic_auth_resp);
        }
        free(auth_credentials);
        free(buf);
    }
    else
    {
        ESP_LOGE(TAG, "No auth header received");
        httpd_resp_set_status(req, HTTPD_401);
        httpd_resp_set_type(req, "application/json");
        httpd_resp_set_hdr(req, "Connection", "keep-alive");
        httpd_resp_set_hdr(req, "WWW-Authenticate", "Basic realm=\"Hello\"");
        httpd_resp_send(req, NULL, 0);
    }

    return ESP_OK;
}

static httpd_uri_t basic_auth = {
    .uri = "/basic_auth",
    .method = HTTP_GET,
    .handler = basic_auth_get_handler,
};

static void httpd_register_basic_auth(httpd_handle_t server)
{
    basic_auth_info_t *basic_auth_info = calloc(1, sizeof(basic_auth_info_t));
    if (basic_auth_info)
    {
        basic_auth_info->username = CONFIG_EXAMPLE_BASIC_AUTH_USERNAME;
        basic_auth_info->password = CONFIG_EXAMPLE_BASIC_AUTH_PASSWORD;

        basic_auth.user_ctx = basic_auth_info;
        httpd_register_uri_handler(server, &basic_auth);
    }
}
#endif
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

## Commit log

2023-02-05 Added prototyped boards
    [ESP_Module-B_Mask.gbr, ESP_Module-B_Paste.gbr, ESP_Module-B_Silkscreen.gbr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]
2023-02-05 Finished prototyped module
    [ESP_Module-B_Mask.gbr, ESP_Module-B_Paste.gbr, ESP_Module-B_Silkscreen.gbr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]
2023-02-08 Added ESP SoC PCB Files
    [ESP_Module-B_Mask.gbr, ESP_Module-B_Paste.gbr, ESP_Module-B_Silkscreen.gbr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]
2023-02-10 Finished PCB prototypes and BOM
    [ESP_SoC-B_Mask.gbr, ESP_SoC-B_Paste.gbr, ESP_SoC-B_Silkscreen.gbr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]
2023-02-15 Added ap + ws
    [ESP_SoC.kicad_pcb]
2023-02-16 Implemented ap + ws + usb hid backend
    [ESP_SoC.kicad_sch, ESP_SoC_lcsc.csv, ESP_SoC_mouser.csv]
2023-02-19 Fixed HID input + began pm
    [main.c]
2023-02-22 Added partitions
    [partitions.csv]
2023-02-27 add a multiple choice button
2023-02-27 add button for all html
2023-03-02 update some photos and pcb info
2023-03-08 fixed delete, still needs to reload
    [main.c]
2023-03-11 Added final PCB design
    [ESP_SoC-B_Mask.gbr, ESP_SoC-B_Paste.gbr, ESP_SoC-B_Silkscreen.gbr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]
2023-03-14 Added default credentials
    [partitions.csv, wch-riscv.cfg]

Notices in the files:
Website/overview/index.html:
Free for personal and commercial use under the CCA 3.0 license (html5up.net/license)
